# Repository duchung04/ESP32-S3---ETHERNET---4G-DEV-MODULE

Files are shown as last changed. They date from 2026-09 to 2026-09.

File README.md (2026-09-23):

ESP32-S3---ETHERNET---4G-DEV-MODULE




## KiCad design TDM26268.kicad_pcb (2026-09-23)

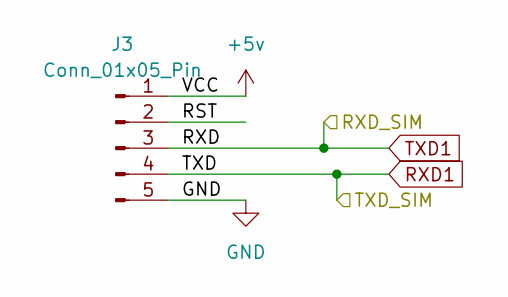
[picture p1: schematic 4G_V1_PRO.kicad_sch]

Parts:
J3: Conn_01x05_Pin; PinHeader_1x05_P2.54mm_Vertical

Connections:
+5v: J3.1; also elsewhere on the board
/4G_V1_PRO/RST: J3.2
GND: J3.5; also elsewhere on the board
RXD1: J3.4; also elsewhere on the board
TXD1: J3.3; also elsewhere on the board

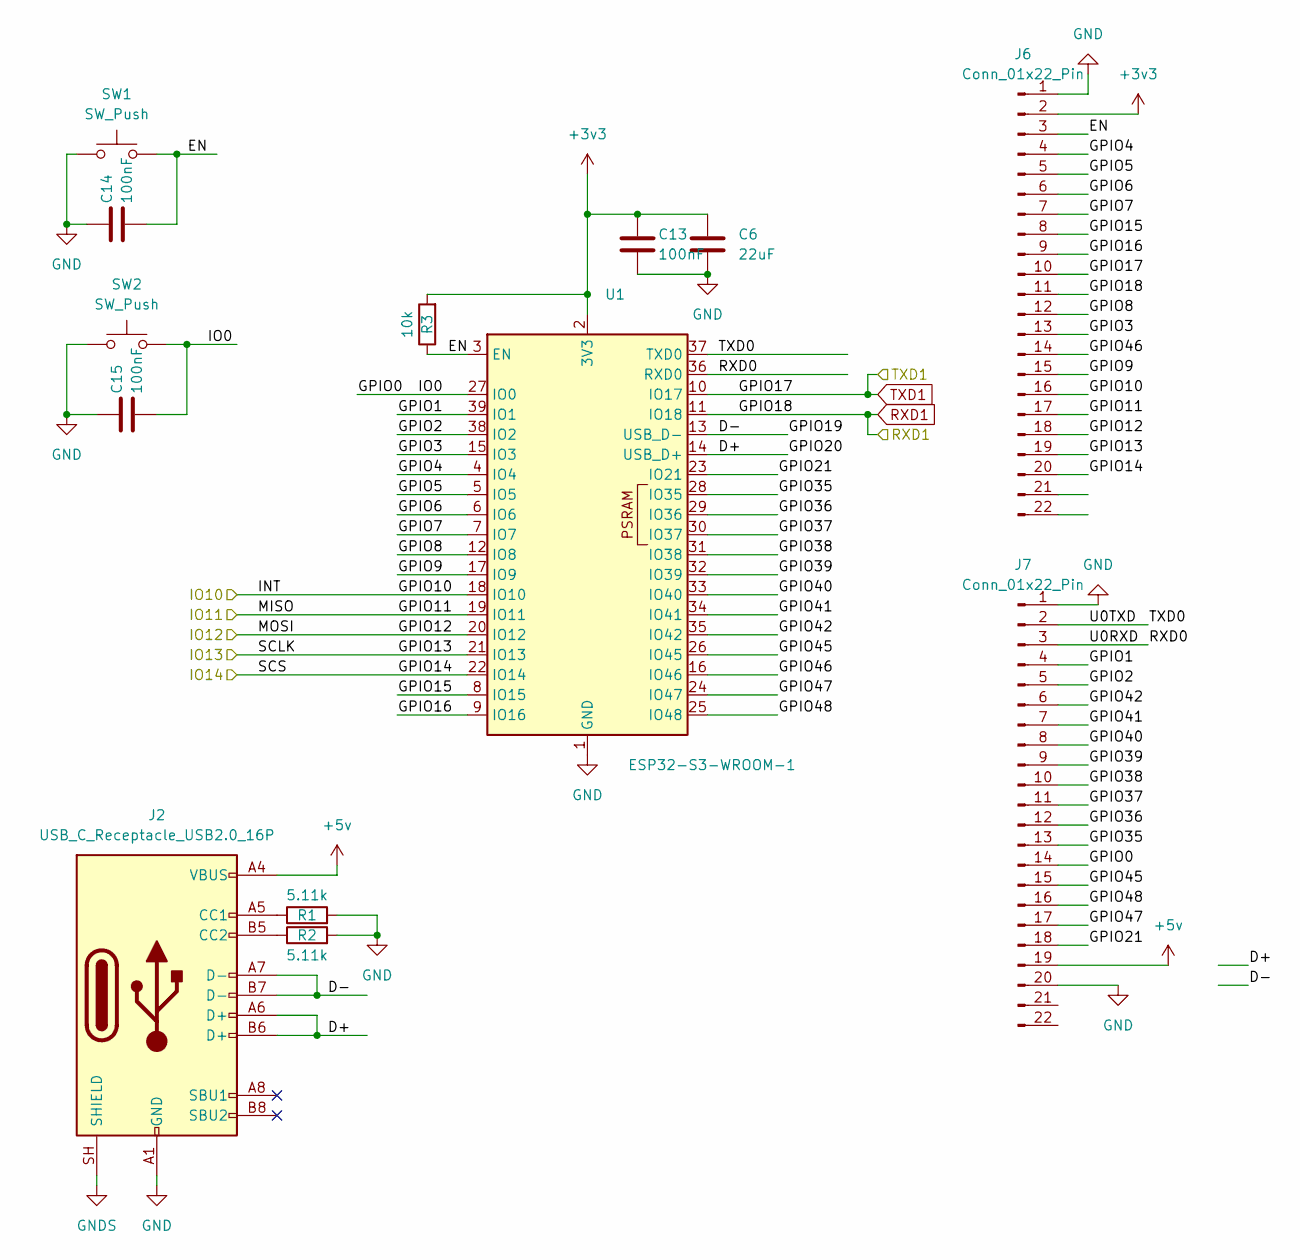
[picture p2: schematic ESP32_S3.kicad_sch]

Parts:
C6: 22uF; C_0805_2012Metric
C13, C14, C15: 100nF; C_0603_1608Metric
J2: USB_C_Receptacle_USB2.0_16P; USB_C_Receptacle_HCTL_HC-TYPE-C-16P-01A
J6, J7: Conn_01x22_Pin; PinHeader_1x20_P2.54mm_Vertical
R1, R2: 5.11k; R_0603_1608Metric
R3: 10k; R_0603_1608Metric
SW1, SW2: SW_Push; SW_SPST_B3U-1000P
U1: ESP32-S3-WROOM-1

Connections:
+3v3: C6.1, C13.1, J6.2, R3.2, U1.2 (3V3); also elsewhere on the board
+5v: J2.A4 (VBUS), J2.A9 (VBUS), J2.B4 (VBUS), J2.B9 (VBUS), J7.19; also elsewhere on the board
/ESP32_S3/D+: J2.A6 (D+), J2.B6 (D+), U1.14 (USB_D+)
/ESP32_S3/D-: J2.A7 (D-), J2.B7 (D-), U1.13 (USB_D-)
/ESP32_S3/EN: C14.2, J6.3, R3.1, SW1.2, U1.3 (EN)
/ESP32_S3/GPIO0: C15.2, J7.14, SW2.2, U1.27 (IO0)
/ESP32_S3/GPIO1: J7.4, U1.39 (IO1)
/ESP32_S3/GPIO2: J7.5, U1.38 (IO2)
/ESP32_S3/GPIO3: J6.13, U1.15 (IO3)
/ESP32_S3/GPIO4: J6.4, U1.4 (IO4)
/ESP32_S3/GPIO5: J6.5, U1.5 (IO5)
/ESP32_S3/GPIO6: J6.6, U1.6 (IO6)
/ESP32_S3/GPIO7: J6.7, U1.7 (IO7)
/ESP32_S3/GPIO8: J6.12, U1.12 (IO8)
/ESP32_S3/GPIO9: J6.15, U1.17 (IO9)
/ESP32_S3/GPIO10: J6.16, U1.18 (IO10); also elsewhere on the board
/ESP32_S3/GPIO11: J6.17, U1.19 (IO11); also elsewhere on the board
/ESP32_S3/GPIO12: J6.18, U1.20 (IO12); also elsewhere on the board
/ESP32_S3/GPIO13: J6.19, U1.21 (IO13); also elsewhere on the board
/ESP32_S3/GPIO14: J6.20, U1.22 (IO14); also elsewhere on the board
/ESP32_S3/GPIO15: J6.8, U1.8 (IO15)
/ESP32_S3/GPIO16: J6.9, U1.9 (IO16)
/ESP32_S3/GPIO21: J7.18, U1.23 (IO21)
/ESP32_S3/GPIO35: J7.13, U1.28 (IO35)
/ESP32_S3/GPIO36: J7.12, U1.29 (IO36)
/ESP32_S3/GPIO37: J7.11, U1.30 (IO37)
/ESP32_S3/GPIO38: J7.10, U1.31 (IO38)
/ESP32_S3/GPIO39: J7.9, U1.32 (IO39)
/ESP32_S3/GPIO40: J7.8, U1.33 (IO40)
/ESP32_S3/GPIO41: J7.7, U1.34 (IO41)
/ESP32_S3/GPIO42: J7.6, U1.35 (IO42)
/ESP32_S3/GPIO45: J7.15, U1.26 (IO45)
/ESP32_S3/GPIO46: J6.14, U1.16 (IO46)
/ESP32_S3/GPIO47: J7.17, U1.24 (IO47)
/ESP32_S3/GPIO48: J7.16, U1.25 (IO48)
/ESP32_S3/RXD0: J7.3, U1.36 (RXD0)
/ESP32_S3/TXD0: J7.2, U1.37 (TXD0)
GND: C6.2, C13.2, C14.1, C15.1, J2.A1 (GND), J2.A12 (GND), J2.B1 (GND), J2.B12 (GND), J6.1, J7.1, J7.20, R1.2, R2.2, SW1.1, SW2.1, U1.1 (GND), U1.40 (GND), U1.41 (GND); also elsewhere on the board
GNDS: J2.SH (SHIELD); also elsewhere on the board
unnamed: J2.A5 (CC1), R1.1
unnamed: J2.B5 (CC2), R2.1
RXD1: J6.11, U1.11 (IO18); also elsewhere on the board
TXD1: J6.10, U1.10 (IO17); also elsewhere on the board

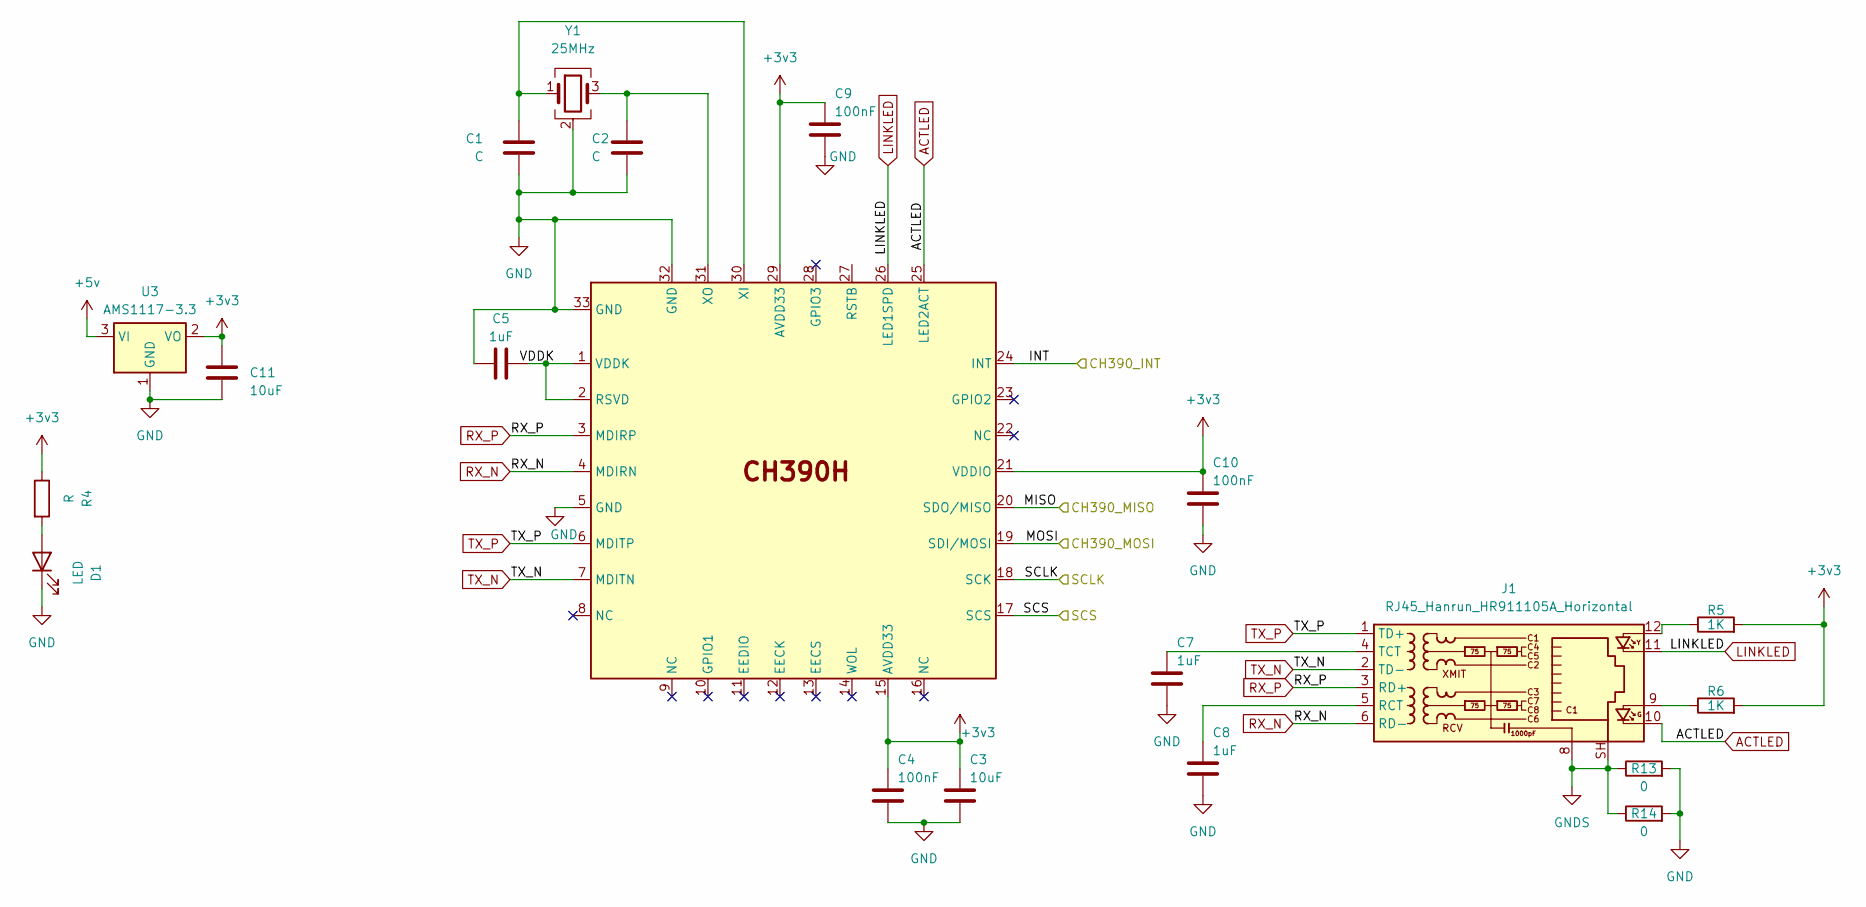
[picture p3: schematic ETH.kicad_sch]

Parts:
C1, C2: C; C_0603_1608Metric
C3: 10uF; C_0805_2012Metric
C4, C9, C10: 100nF; C_0603_1608Metric
C5, C7, C8: 1uF; C_0603_1608Metric
C11: 10uF; C_0805_2012Metric_Pad1.18x1.45mm_HandSolder
D1: LED; LED_0603_1608Metric
J1: RJ45_Hanrun_HR911105A_Horizontal
R4: R; R_0603_1608Metric
R5, R6: 1K; R_0603_1608Metric
R13, R14: 0; R_1206_3216Metric
U3: AMS1117-3.3; SOT-223-3_TabPin2
U4: CH390D; QFN-32-1EP_5x5mm_P0.5mm_EP3.3x3.3mm_ThermalVias
Y1: 25MHz; Crystal_SMD_3225-4Pin_3.2x2.5mm

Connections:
+3v3: C3.1, C4.1, C9.1, C10.1, C11.1, R4.1, R5.2, R6.2, U3.2 (VO), U4.15 (AVDD33), U4.21 (VDDIO), U4.29 (AVDD33); also elsewhere on the board
+5v: U3.3 (VI); also elsewhere on the board
/ESP32_S3/GPIO10: U4.24 (INT); also elsewhere on the board
/ESP32_S3/GPIO11: U4.20 (SDO/MISO); also elsewhere on the board
/ESP32_S3/GPIO12: U4.19 (SDI/MOSI); also elsewhere on the board
/ESP32_S3/GPIO13: U4.18 (SCK); also elsewhere on the board
/ESP32_S3/GPIO14: U4.17 (SCS); also elsewhere on the board
/ETH/VDDK: C5.2, U4.1 (VDDK), U4.2 (RSVD)
ACTLED: J1.10, U4.25 (LED2ACT)
GND: C1.2, C2.2, C3.2, C4.2, C5.1, C7.2, C8.2, C9.2, C10.2, C11.2, D1.1 (K), R13.2, R14.2, U3.1 (GND), U4.5 (GND), U4.32 (GND), U4.33 (GND), Y1.2 (G), Y1.4 (G); also elsewhere on the board
GNDS: J1.8, J1.SH, R13.1, R14.1; also elsewhere on the board
LINKLED: J1.11, U4.26 (LED1SPD)
unnamed: D1.2 (A), R4.2
unnamed: J1.9, R6.1
unnamed: J1.12, R5.1
unnamed: C8.1, J1.5 (RCT)
unnamed: C7.1, J1.4 (TCT)
unnamed: C1.1, U4.30 (XI), Y1.1
unnamed: C2.1, U4.31 (XO), Y1.3
RX_N: J1.6 (RD-), U4.4 (MDIRN)
RX_P: J1.3 (RD+), U4.3 (MDIRP)
TX_N: J1.2 (TD-), U4.7 (MDITN)
TX_P: J1.1 (TD+), U4.6 (MDITP)

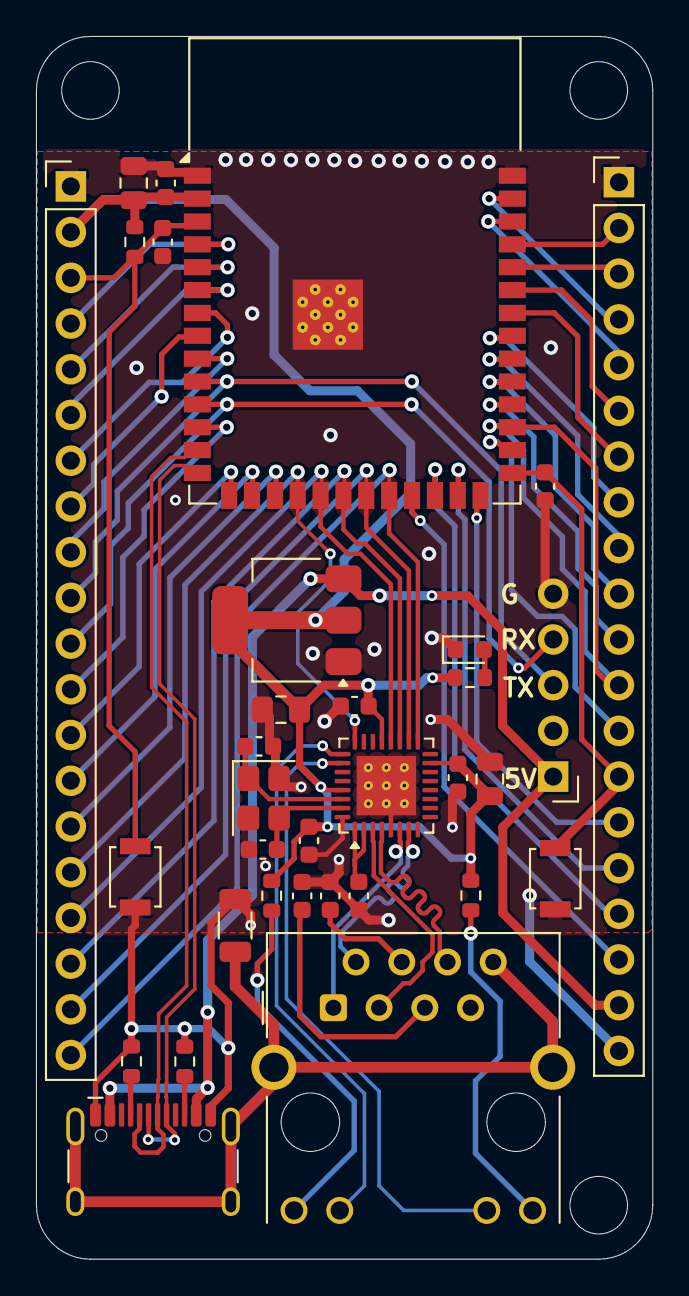
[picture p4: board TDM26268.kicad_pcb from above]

Board: 2 copper layers, 34.2 x 67.9 mm, 33 parts (0 on the bottom side), 57 nets.
